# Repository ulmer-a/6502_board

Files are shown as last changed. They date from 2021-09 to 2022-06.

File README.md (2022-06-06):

# Homebrew 6502 single board computer (running MS BASIC)

This repo contains kicad schematics, netlist, layout and gerber plots for the pcb,
as well as a parts list, the firmware and a port of Microsoft BASIC. The board is
fully functional and all parts (or equivalent alternatives) are readily available
as of Nov '21.

You are welcome to use everything contained in this repository under the
terms of the GNU General Public License v3.0, except for MS BASIC, which is
made available under a BSD 2-clause license.

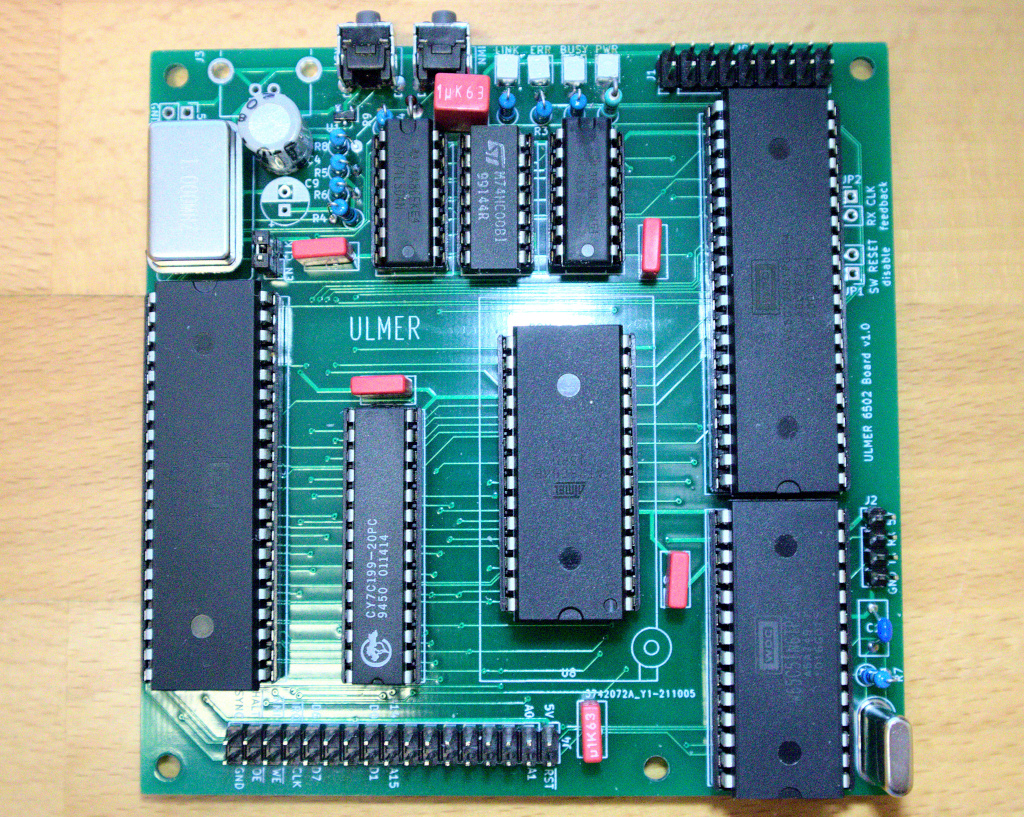
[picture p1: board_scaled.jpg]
PCB Rendering


## Specifications

* 65c02 8-bit CPU along with 32KB RAM and 8K ROM
* 65c22 VIA provides some GPIO pins and timers
* 65c51 ACIA provides a serial port with up to 115200 baud
* 4 status led's (3 of them are freely programmable)
* 18 pin I/O pinheader with general purpose I/O pins (VIA)
* 34 pin expansion pinheader exposing full address and data bus
as well as other interesting lines (`SYNC`, `CLK` and `HALT`)

## Firmware

The firmware initializes the system and provides drivers for the
GPIOs, timers and the UART. It also provides routines to support
the execution of MS BASIC.

## Memory map and I/O addresses

```plaintext
+-----------------------+   <- 0x0000     --.
|       zeropage        |                   |
+-----------------------+   <- 0x0100       |
|        stack          |                   |
+-----------------------+   <- 0x0200       |
|      available        |                   |
|         RAM           |                    > 32k RAM
|         ...           |                   |
+-----------------------+   <- 0x7e00       |
|     UART RX buffer    |                   |
+-----------------------+   <- 0x7f00       |
|     UART TX buffer    |                   |
+-----------------------+   <- 0x8000     --'
|                       |
|      unallocated      |         reserved for expansion shields etc.
|                       |
+-----------------------+   <- 0xdfe0     --.
|      65C51 UART       |                   |
+-----------------------+   <- 0xdff0        > memory mapped I/O
|      65C22 VIA        |                   |
+-----------------------+   <- 0xe000     --:
|     firmware code     |                   |
|    firmware rodata    |                   |
|       MS BASIC        |                    > 8k ROM
+-----------------------+   <- 0xfffa       |
|   reset/irq vectors   |                   |
+-----------------------+   <- 0xffff     --'
```

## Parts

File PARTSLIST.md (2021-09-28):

# Parts list

## Main components
* WDC W65C02 CPU
* WDC W65C51 UART
* WDC W65C22 VIA IO

## RAM/ROM
* AT28C64B EEPROM
* CY7C199 32K RAM

## Decoder logic
* 74LS30 8-Input NAND
* 74LS00 Quad NAND
* 74LS04 Hex INVERTER
* DS1813 integrated RESET circuitry

## Pinheader & jacks
* Pinheader 2x9 2.54mm (IO pins)
* Pinheader 2x17 2.54mm (Expansion Port)
* Pinheader 1x4 2.54mm (UART)
* Mini USB B type (power)

## Oscillators, crystals
* 1.8432 MHz Quartz crystal (uart)
* 1MHz Can oscillator DIP14 (main clock)

## Resistors, capacitors
* 3x ~300Ohm (LED's)
* 3x ~3.3k (Pullup)
* 4x 100n support capacitors

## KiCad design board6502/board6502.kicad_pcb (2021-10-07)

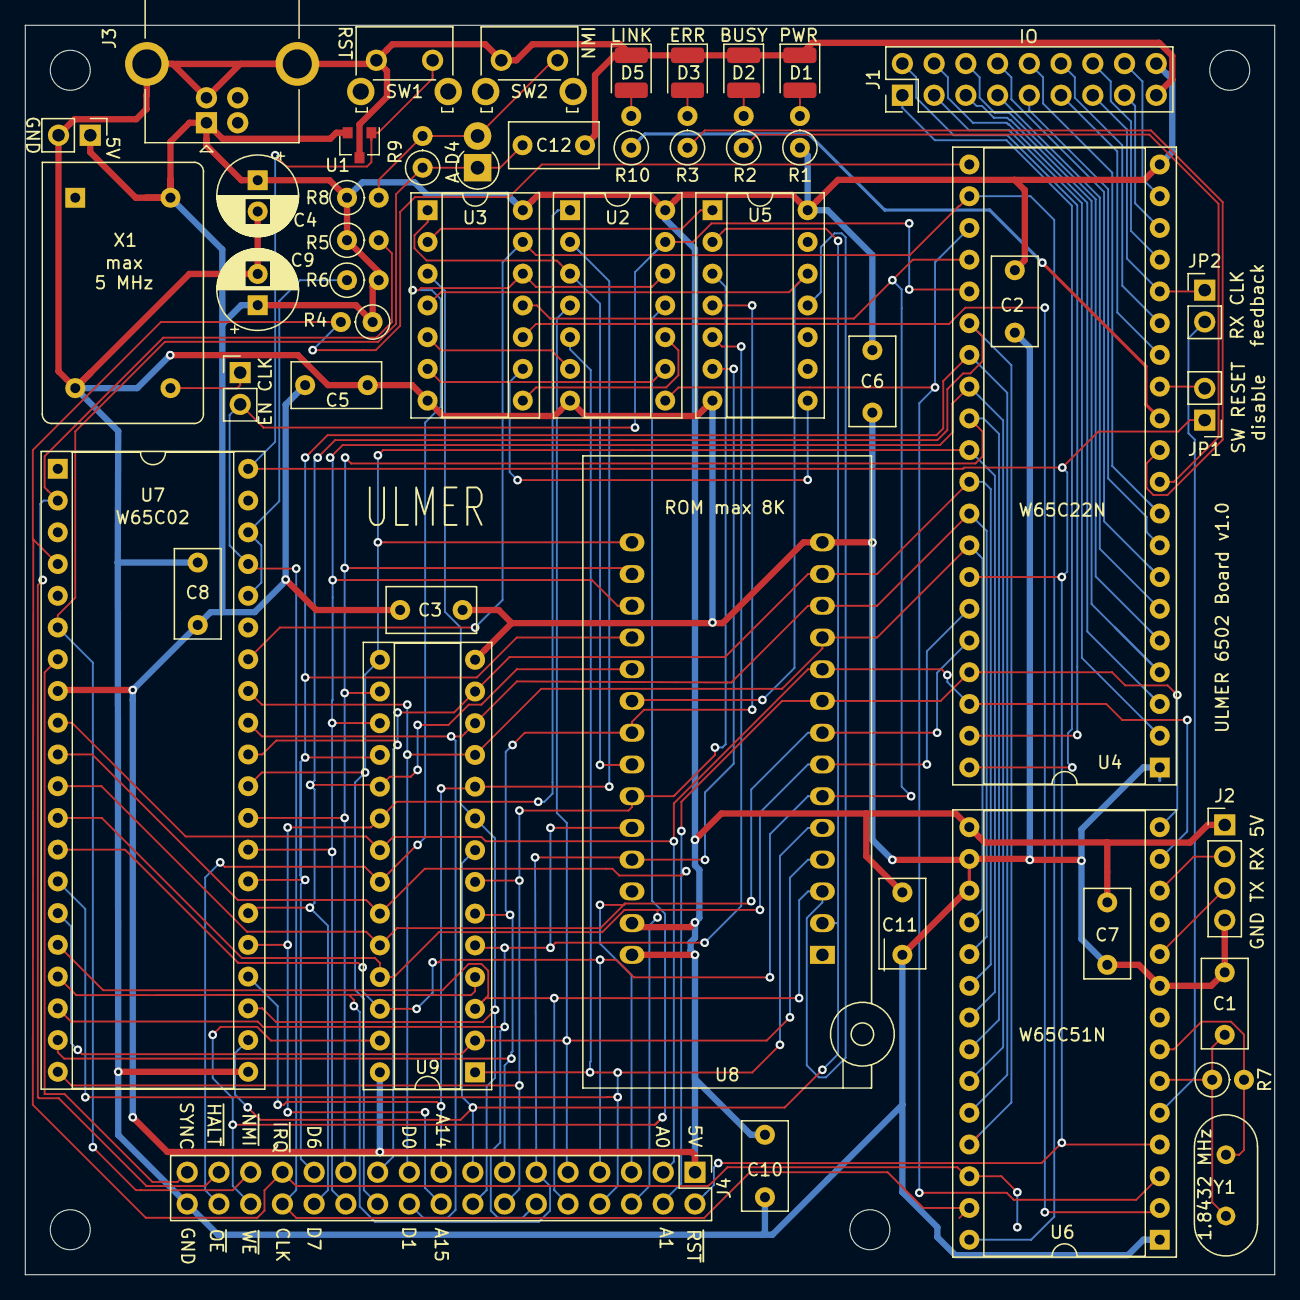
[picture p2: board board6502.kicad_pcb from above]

Board: 2 copper layers, 100.0 x 100.0 mm, 52 parts (0 on the bottom side), 76 nets.

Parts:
C1: 27p; C_Rect_L7.0mm_W3.5mm_P5.00mm
C2, C3, C5, C6, C7, C8, C10, C11: 100n; C_Rect_L7.0mm_W3.5mm_P5.00mm
C4, C9: 100µ; CP_Radial_D6.3mm_P2.50mm
C12: tbd; C_Rect_L7.0mm_W3.5mm_P5.00mm
D1, D2, D3, D5: LED_Small; LED_1210_3225Metric
D4: tbd; D_DO-41_SOD81_P2.54mm_Vertical_AnodeUp
J1: IO Pinheader; PinHeader_2x09_P2.54mm_Vertical
J2: UART; PinHeader_1x04_P2.54mm_Vertical
J3: USB_B; USB_B_OST_USB-B1HSxx_Horizontal
J4: Expansion Port; PinHeader_2x17_P2.54mm_Vertical
J5: Power connector; PinHeader_1x02_P2.54mm_Vertical
JP1: SW Reset; PinHeader_1x02_P2.54mm_Vertical
JP2: RXCLK feed; PinHeader_1x02_P2.54mm_Vertical
JP3: CLK disable; PinHeader_1x02_P2.54mm_Vertical
M3, M3#2, M3#3, M3#4: MountingHole_3.2mm_M3
R1, R2, R3, R10: 330; R_Axial_DIN0207_L6.3mm_D2.5mm_P2.54mm_Vertical
R4, R5, R6, R8: pullup; R_Axial_DIN0207_L6.3mm_D2.5mm_P2.54mm_Vertical
R7: 1M; R_Axial_DIN0207_L6.3mm_D2.5mm_P2.54mm_Vertical
R9: tbd; R_Axial_DIN0207_L6.3mm_D2.5mm_P2.54mm_Vertical
SW1: Reset button; SW_Tactile_SKHH_Angled
SW2: SW_NMI; SW_Tactile_SKHH_Angled
U1: DS1813; SOT-23
U2: 74LS00; DIP-14_W7.62mm_Socket
U3: 74LS04; DIP-14_W7.62mm_Socket
U4: W65C22N; DIP-40_W15.24mm_Socket
U5: 74LS30; DIP-14_W7.62mm_Socket
U6: W65C51N; DIP-28_W15.24mm_Socket
U7: W65C02; DIP-40_W15.24mm_Socket
U8: AT28C64B; DIP_Socket-28_W11.9_W12.7_W15.24_W17.78_W18.5_3M_228-1277-0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
U9: CY7C199; DIP-28_W7.62mm_Socket
X1: 1-10MHz; Oscillator_DIP-14
Y1: 1.8432M; Crystal_HC18-U_Vertical

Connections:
+5V: C2.1, C3.2, C4.1, C5.1, C6.2, C7.1, C8.2, C9.1, C10.1, C11.2, J1.18, J2.1, J3.1, J4.1, J5.1, R1.1, R4.1, R5.1, R6.2, R8.1, U1.2, U2.14, U3.14, U4.20, U5.14, U6.15, U7.8, U8.27, U8.28, U9.28, X1.14
A0: J4.3, U4.38, U6.13, U7.9, U8.10, U9.21
A1: J4.4, U4.37, U6.14, U7.10, U8.9, U9.23
A2: J4.5, U4.36, U7.11, U8.8, U9.24
A3: J4.6, U4.35, U7.12, U8.7, U9.25
A4: J4.7, U3.11, U4.24, U7.13, U8.6, U9.26
A5: J4.8, U2.5, U7.14, U8.5, U9.1
A6: J4.9, U2.4, U7.15, U8.4, U9.2
A7: J4.10, U5.11, U7.16, U8.3, U9.3
A8: J4.11, U5.6, U7.17, U8.25, U9.4
A9: J4.12, U5.5, U7.18, U8.24, U9.5
A10: J4.13, U5.4, U7.19, U8.21, U9.6
A11: J4.14, U5.3, U7.20, U8.23, U9.7
A12: J4.15, U5.2, U7.22, U8.2, U9.8
A13: J4.16, U3.3, U7.23, U9.9
A14: J4.17, U2.2, U7.24, U9.10
A15: J4.18, U2.1, U7.25, U9.20
CLK: J4.28, JP3.2, U2.13, U4.25, U6.27, U7.37
CS_UART: U3.10, U6.2
D0: J4.19, U4.33, U6.18, U7.33, U8.11, U9.11
D1: J4.20, U4.32, U6.19, U7.32, U8.12, U9.12
D2: J4.21, U4.31, U6.20, U7.31, U8.13, U9.13
D3: J4.22, U4.30, U6.21, U7.30, U8.15, U9.15
D4: J4.23, U4.29, U6.22, U7.29, U8.16, U9.16
D5: J4.24, U4.28, U6.23, U7.28, U8.17, U9.17
D6: J4.25, U4.27, U6.24, U7.27, U8.18, U9.18
D7: J4.26, U4.26, U6.25, U7.26, U8.19, U9.19
GND: C1.2, C2.2, C3.1, C4.2, C5.2, C6.1, C7.2, C8.1, C9.2, C10.2, C11.1, C12.2, D1.1, D2.1, D3.1, D5.1, J1.17, J2.4, J3.4, J3.5, J4.34, J5.2, SW1.1, SW2.1, U1.3, U2.7, U3.7, U4.1, U5.7, U6.1, U6.9, U6.16, U6.17, U7.21, U8.14, U9.14, X1.7
IO1: J1.1, U4.40
IO2: J1.2, U4.39
IO3: J1.3, U4.2
IO4: J1.4, U4.3
IO5: J1.5, U4.4
IO6: J1.6, U4.5
IO7: J1.7, U4.6
IO8: J1.8, U4.7
IO9: J1.9, U4.8
IO10: J1.10, U4.9
IO11: J1.11, U4.14
IO12: J1.12, U4.15
IO13: J1.13, JP2.1, U4.16
IO14: J1.14, U4.17
IO15: J1.15, U4.18
IO16: J1.16, U4.19
LED1: R2.1, U4.10
LED2: R3.1, U4.11
LED3: R10.1, U4.12
unnamed: C1.1, R7.1, U6.6, Y1.1
unnamed: D1.2, R1.2
unnamed: D2.2, R2.2
unnamed: D3.2, R3.2
unnamed: D4.2, R8.2, R9.2, SW2.2
unnamed: D5.2, R10.2
unnamed: JP3.1, X1.8
unnamed: R6.1, U7.36, U7.38
unnamed: R7.2, U6.7, Y1.2
unnamed: U2.6, U3.5
unnamed: U2.9, U3.6
unnamed: U2.10, U3.8
unnamed: U3.2, U5.1
unnamed: U3.9, U5.8
RW_: U3.13, U4.22, U6.28, U7.34
RXCLK: JP2.2, U6.5
SYNC: J4.33, U7.7
UART_RX: J2.2, U6.12
UART_TX: J2.3, U6.10
_CS_ROM: U3.4, U5.12, U8.20
_HALT: J4.31, R5.2, U7.2
_IOSPACE: U2.3, U3.1, U8.22
_IO_CS: U2.8, U4.23, U6.3
_IRQ: J4.27, R4.2, U4.21, U6.26, U7.4
_NMI: C12.1, D4.1, J4.29, R9.1, U7.6
_OE: J4.32, U2.12, U3.12, U9.22
_RESET: J4.2, JP1.1, SW1.2, U1.1, U4.34, U6.4, U7.40
_SW_RESET: JP1.2, U4.13
_WE: J4.30, U2.11, U9.27

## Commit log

2021-09-25 wire up address and data bus of Z80 CPU
    [z80.kicad_pcb, z80.sch]
2021-09-25 add 8K EEPROM chip to library
    [z80.sch]
2021-09-25 wire up EEPROM
    [z80.sch]
2021-09-25 map EEPROM into address space
    [z80.sch]
2021-09-25 wire up config register
    [z80.sch]
2021-09-25 update ROM circuit
    [z80.sch]
2021-09-25 wire up 65c02 cpu
    [z80.sch]
2021-09-25 wire up new CS for the ROM
    [z80.sch]
2021-09-25 wire up static RAM
    [z80.sch]
2021-09-25 add uart chip w65c51
    [z80.sch]
2021-09-25 add address decoding logic
    [z80.sch]
2021-09-25 wire up VIA
    [z80.sch]
2021-09-25 add caption for VIA
    [z80.sch]
2021-09-26 add reset and power supply circuits
    [z80.sch]
2021-09-26 remove VIA again
    [z80.sch]
2021-09-27 replace barrel jack with micro usb
    [z80.sch]
2021-09-27 rearrange some components
    [z80.sch]
2021-09-27 wire up the 65c22
    [z80.sch]
2021-09-27 complete VIA interface
    [z80.sch]
2021-09-27 make IRQ line wired-or
    [z80.sch]
2021-09-27 new reset circuit
    [z80.sch]
2021-09-27 complete RAM wiring
    [z80.sch]
2021-09-27 rearrange ROM
    [z80.sch]
2021-09-27 rearrange CPU
    [z80.sch]
2021-09-27 wire up UART baud rate generator
    [z80.sch]
2021-09-27 add IO expansion port
    [z80.sch]
2021-09-27 arrange power supply
    [z80.sch]
2021-09-27 address decoding
    [z80.sch]
2021-09-27 fix 6551 crystal
    [z80.sch]
2021-09-27 add RXCLK line to PB6 of VIA
    [z80.sch]
2021-09-27 annotate all parts
    [z80.sch]
2021-09-27 fix small errors
    [z80.sch]
2021-09-27 rename from z80 to 6502
    [board6502.kicad_pcb, board6502.sch]
2021-09-27 update IO memory addresses
    [board6502.sch]
2021-09-27 update MMIO addresses
    [board6502.sch]
2021-09-28 add HALT/SNYC lines to implement hardware debugger
    [board6502.sch]
2021-09-28 update gitignore for kicad pcb
    [board6502.kicad_pcb, board6502.sch]
2021-09-28 nicer arrangement of commponents
    [board6502.sch]
2021-09-30 add 1M on UART clk
    [board6502.sch]
2021-09-30 update power supply stabilization
    [board6502.sch]
2021-09-30 add NMI button
    [board6502.sch]
2021-09-30 add values
    [board6502.sch]
2021-09-30 start assigning footprints
    [board6502.sch]
2021-09-30 preliminary footprint assignment
    [board6502.sch]
2021-09-30 add power led
    [board6502.sch]
2021-09-30 add vga connector
    [vgaboard.kicad_pcb, vgaboard.sch]
2021-09-30 add horizontal counter
    [vgaboard.sch]
2021-09-30 generate HSYNC
    [vgaboard.sch]
2021-09-30 save progress on vgaboard
    [vgaboard.sch]
2021-09-30 remove vga board experiments
    [vgaboard.kicad_pcb, vgaboard.sch]
2021-10-01 add second power port
    [board6502.sch]
2021-10-01 annotate, complete up
    [board6502.sch]
2021-10-01 add PCB
    [board6502.kicad_pcb]
2021-10-01 start laying out components
    [board6502.kicad_pcb, board6502.sch]
2021-10-01 complete layout
    [board6502.kicad_pcb]
2021-10-02 update trace and via sizes
    [board6502.kicad_pcb]
2021-10-02 update net classes
    [board6502.kicad_pcb]
2021-10-02 finally complete PCB routing
    [board6502.kicad_pcb]
2021-10-03 revisit power lines
    [board6502.kicad_pcb]
2021-10-03 redo led traces
    [board6502.kicad_pcb]
2021-10-03 satisfy design rules
    [board6502.kicad_pcb]
2021-10-03 move silkscreen out of the way
    [board6502.kicad_pcb]
2021-10-03 add mounting holes
    [board6502.kicad_pcb]
2021-10-03 fix design rule violation
    [board6502.kicad_pcb]
2021-10-03 add component annotation
    [board6502.kicad_pcb]
2021-10-03 annotate expansion bus
    [board6502.kicad_pcb]
2021-10-07 plot gerber files
    [board6502-B_Cu.gbr, board6502-B_Mask.gbr, board6502-B_SilkS.gbr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]
2021-10-31 update firmware: read UART in IRQ mode
2021-11-30 rewrite firmware for rust assembler
2021-12-02 progress on uart driver
2021-12-02 reformat uart driver code
2021-12-02 make board boot with the current firmware
2021-12-02 make UART receive work
2021-12-02 reformat uart code
2021-12-02 add documentation comments to the uart driver
2021-12-03 add seperate source file for i/o driver
2021-12-03 setup via interrupt handling
2021-12-03 implement buffer-fed timer-driven uart transmit
2021-12-03 fine-tune timer value for uart transmit timer
2021-12-03 split up parts of uart.S into stdio.S
2021-12-04 replace rendering with actual assembled board
